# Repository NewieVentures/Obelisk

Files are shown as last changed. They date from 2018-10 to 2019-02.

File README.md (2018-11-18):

# Project Faraday
### By NewieVentures

Remote control of LED strip lights via DMX over cellular.

## Hardware
### Artifacts
* FP1 - Motherboard
* FP2 - DMX expansion module
* FA1 - Assembled unit
* FA2 - Demonstration panel

## LED patterns
To update the pattern of an active device, the device ID and a valid access token is required:

`curl -v "https://api.particle.io/v1/devices/<DEVICE_ID>/<function>" -d access_token=<TOKEN> -d arg=<ARG>`

eg to set a green strobe at 1Hz:

`curl -v "https://api.particle.io/v1/devices/<your device ID here>/strobe" -d access_token=<your access token here> -d arg="1000,#00FF00"`

### Blink
Flash LEDs on and off. Duty cycle controls amount of time on vs off.
#### Arguments
`"<period (ms)>,<duty cycle (0-100)>,<colour-on>,<colour-off>"`

eg blink red 1s:

`POST /v1/devices/:deviceId/blink { "arg": "1000,50,#FF0000,#000000" }`

### Colour
Fixed colour on all leds
#### Arguments
`"<colour>"`

Eg all LEDS blue:

`POST /v1/devices/:deviceId/colour { "arg": "#0000FF" }`

### Gradient
Linear colour gradient
#### Arguments
`"<start-colour>,<end-colour>"`

eg gradient on all LEDS from red to green:

`POST /v1/devices/:deviceId/gradient { "arg": "#FF0000,#00FF00" }`

### Progress
Progress bar
#### Arguments
* Initial value: 0 - (# leds – 1)
* Final value: 1 - #leds
* Direction: 0 = first LED to last, 1 = last LED to first

`"<initial value>,<final value><increment (# leds)>,<increment delay (ms)>,<reset delay(ms)>,<direction>,<colour-on>,<colour-off>"`

eg Progress bar from 0 to 100 leds with 1s between increments, 5s pause at the final value
before repeating and starting from the first LED to the last, incrementing by 1 LED with
RED being on and black being off:

```
POST /v1/devices/:deviceId/progress
{ "arg": "0,100,1,1000,5000,0,#FF0000,#000000" }
```

### Snake
Block of LEDS moving along the strip.
#### Arguments
* Direction: 0 = first LED to last, 1 = last LED to first
`"<period (ms)>,<direction>,<length (# leds)>,<colour-on>,<colour-off>"`

eg Green block of 3 LEDS moving from first LED to last every 5s on a black background:

`POST /v1/devices/:deviceId/snake { "arg": "5000,0,3,#00FF00,#000000" }`

### Strobe
Flash LEDs
#### Arguments
`"<period (ms)>,<colour>"`

eg Blue flash at 1Hz

`POST /v1/devices/:deviceId/strobe { "arg": "1000,#0000FF" }`

## Firmware
The firmware is compiled using the particle cloud development tools (internet connection required).

### Setup
Install the particle CLI, see docs at
https://docs.particle.io/tutorials/developer-tools/cli/

### Compiling
To compile using the particle CLI:
`particle compile electron app --saveTo electron.bin`

### Flashing
To flash a binary to the module over USB, put it into programming mode then:
`particle flash --usb electron.bin`

### Unit tests
```
cd src
make tests && ./tests
```

### Structure
The firmware runs on a Particle Electron board, using their Device OS.  The major firmware modules are:
* cloudFunctions - functions registered with Particle's Device OS on boot and called via their cloud interface.
* LedStripDriver - generates colour values for each LED based on the pattern and settings.  The cloud functions change the pattern settings, while a timer in the RTOS calls the onTimerFired() method to process the new values.
* dmx - uses Serial1 to send the DMX packets (requires some low level override of the baud rate to send the break and mark-after-break at the start of the packet) and sends the NULL start code in each packet.

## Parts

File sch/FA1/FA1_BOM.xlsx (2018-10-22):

Refs | Description | Manufacturer | Order Number | Part Number | Supplier | Quantity | Price | Subtotal | Notes
D1 | LED PANEL INDICATOR RED 1.8V IP67 | E-Switch | EG5379-ND | PVL16FLS11 | Digikey | 1 | $16.49 | $16.49
D2 | LED PANEL INDICATOR BLUE 2.8V IP67 | E-Switch | EG5381-ND | PVL16FLS41 | Digikey | 1 | $16.49 | $16.49
J1 | PWR ENT RCPT IEC320-C14 PANEL QC | Qualtek | Q212-ND | 703W-00/04 | Digikey | 1 | $1.19 | $1.19
J2 | CONN SMA JACK STR 50 OHM SOLDER | Amphenol | ACX1183-ND | 132105 | Digikey | 1 | $11.94 | $11.94
J3 | TERM BLK HEADER 4POS GREEN | Phoenix Contact | 277-6689-ND | 1899155 | Digikey | 1 | $6.49 | $6.49
U1 | FP1 sub-assembly |  |  |  |  | 1 |  | $0.00
U2 | AC/DC CONVERTER 5V 5W | Mean Well | 1866-5411-ND | PS-05-5 | Digikey | 1 | $9.64 | $9.64 | Not required if using PSU on FP1
 | IP65 Sealed ABS enclosure 222x146x55mm | Multicomp | HB-6130 | MC001120 | Jaycar | 1 | $24.95 | $24.95
 | CONN HOUSING VH 2POS 3.96MM WHT | JST | 455-1183-ND | VHR-2N | Digikey | 3 | $0.17 | $0.51
 | CONN HOUSING VH 3POS 3.96MM WHT | JST | 455-1184-ND | VHR-3N | Digikey | 1 | $0.20 | $0.20
 | CONN TERM CRIMP VH/NV 18-22AWG | JST | 455-1133-1-ND | SVH-21T-P1.1 | Digikey | 9 | $0.16 | $1.44
 | Wire |  |  |  |  |  |  |  | Used for LEDs, IEC, SMA and DMX
 | ANT LTE BLADE SWIVEL DIPOLE SMA | Linx Technologies | ANT-LTE-WS-SMA-ND | ANT-LTE-WS-SMA | Digikey | 1 | $13.62 | $13.62
 | Screw M3 x 6mm Pan SS |  |  |  |  | 4 |  | $0.00
 | Washer Flat M3 SS |  |  |  |  | 4 |  | $0.00
 | Screw M3 x 10mm Pan SS |  |  |  |  | 4 |  | $0.00
 | Nut M3 SS |  |  |  |  | 4 |  | $0.00
 | Washer Spring M3 SS |  |  |  |  | 4 |  | $0.00
 | TERM BLOCK PLUG 4POS STR 5.08MM | Phoenix Contact | 277-5925-ND | 1780002 | Digikey | 1 | $8.88 | $8.88
 | CBL ASSY U.FL PLUG to cable 100mm | Hirose Electric Co | H125220-ND | U.FL-LP-066J1-A-(100) | Digikey | 1 | $8.02 | $8.02 | Can use cable from kit (de-solder from PCB antenna)
 |  |  |  |  |  |  | Total | $86.88

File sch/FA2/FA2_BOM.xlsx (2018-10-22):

Refs | Description | Manufacturer | Order Number | Part Number | Supplier | Quantity | Price | Subtotal | Notes
U1 | DMX-512 Decoder SPI output 5-24VDC | LTECH | LT-DMX-1809 | LT-DMX-1809 | Agoeu LED Express Store | 1 | $34.11 | $34.11
U2 | FA1 | Newie Ventures |  |  |  | 1 |  | $0.00
U3 | AC adapter 110-240VAC to 5V 3A DC |  | MP3480 |  | Jaycar | 1 | $24.95 | $24.95
U4, U5 | 5M RGB LED Strip - WS2812 60 Per Meter - White Strip - Weatherproof |  | CE04854 |  | Core Electronics | 0.4 | $69.00 | $27.60
 | Melamine panel |  |  |  |  | 1
 | Power board |  | MS4040 |  | Jaycar | 1 | $5.00 | $5.00
 | IEC cable |  | PS4106 |  |  | 1 | $8.95 | $8.95
 | Screws, wood
 |  |  |  |  |  |  | Total | $91.66

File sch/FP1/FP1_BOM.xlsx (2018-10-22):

Refs | Description | Manufacturer | Order Number | Part Number | Supplier | Quantity | Price | Subtotal | Notes
C1, C5 | CAP CER 1nF 450V C0G 0805 | TDK | 445-15536-1-ND | CGA4C4C0G2W102J060AA | Digikey | 2 | $0.51 | $1.02 | Optional if external 5VDC used
C2 | CAP CER 1UF 50V X7R 0805 | Samsung Electro-mechanics | 1276-6470-1-ND | CL21B105KBFNNNG | Digikey | 1 | $0.20 | $0.20
C3 | CAP ALUM 470UF 20% 10V RADIAL | Kemet | 399-6589-ND | ESH477M010AE3AA | Digikey | 1 | $0.36 | $0.36
C4 | CAP CER 0.1uF 630V X7R 1210 | Kemet | 399-13490-1-ND | C1210C104KBRAC7800 | Digikey | 1 | $0.69 | $0.69
C6 | CAP CER 10UF 10V 10% X5R 0805 | Samsung Electro-mechanics | 1276-2402-1-ND | CL21A106KPCLQNC | Digikey | 1 | $0.30 | $0.30
C7 | CAP CER 0.1UF 50V X7R 0805 | Murata | 490-8049-1-ND | GCM21BR71H104KA37K | Digikey | 1 | $0.33 | $0.33
D1 | TVS DIODE 7Vs 12Vc 600W | Littelfuse | SMBJ7.0ALFCT-ND | SMBJ7.0A | Digikey | 1 | $0.61 | $0.61
F1 | FUSE BOARD MNT 2A 250VAC 125VDC | Schurter | 486-1250-ND | 3403.0169.11 | Digikey | 1 | $0.93 | $0.93 | Optional if external 5VDC used
J1 | CONN HEADER VH TOP 3POS 3.96MM | JST | 455-1640-ND | B3P-VH(LF)(SN) | Digikey | 1 | $0.35 | $0.35 | Optional if external 5VDC used
J2, J4 | CONN HEADER FEMALE 9POS .1\" GOLD | Sullins Connector Solutions | S7042-ND | PPPC091LFBN-RC | Digikey | 4 | $0.97 | $3.88
J3, J5, J6 | CONN HEADER VH TOP 2POS 3.96MM | JST | 455-1639-ND | B2P-VH(LF)(SN) | Digikey | 3 | $0.27 | $0.81
L1 | IND 4.7uH 2A 72 mOHM SMD | Taiyo Yuden | 587-2407-1-ND | NRS5020T4R7MMGJ | Digikey | 1 | $0.49 | $0.49 | Optional if external 5VDC used
L2 | Common Mode Choke 10mH 2A 2 lines through hole | Schaffner | 817-2142-ND | RN143-2-02-10M | Digikey | 1 | $4.18 | $4.18 | Optional if external 5VDC used
PS1 | AC-DC 100-240VAC to 5VDC 2A and 12V 400mA | Mornsun | LHE15-20D0512-04 | LHE15-20D0512-04 | Mornsun | 1 |  | $0.00 | Optional if external 5VDC used
R1, R2 | RES SMD 4.7K OHM 5% 1/8W 0805 | Yageo | 311-4.7KARCT-ND | RC0805JR-074K7L | Digikey | 2 | $0.14 | $0.28
R3, R4 | RES SMD 220 OHM 5% 0.4W 0805 | Rohm | RHM220KCT-ND | ESR10EZPJ221 | Digikey | 2 | $0.14 | $0.28
RV1 | VARISTOR 470V 4.5KA DISC 14MM | Bourns | MOV-14D471K-ND | MOV-14D471K | Digikey | 1 | $0.68 | $0.68 | Optional if external 5VDC used
U1 | Particle Electron 3G Kit | Particle | CE04423 | Electron | Core Electronics | 1 | $135.00 | $135.00
J2, J4 | CONN HEADER FEMALE 4POS .1\" GOLD | Sullins Connector Solutions | S7037-ND | PPPC041LFBN-RC | Digikey | 4 | $0.68 | $2.72
 |  |  |  |  |  |  | Total | $153.11

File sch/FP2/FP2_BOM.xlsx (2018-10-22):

Refs | Description | Manufacturer | Order Number | Part Number | Supplier | Quantity | Price | Subtotal | Notes
C1 | CAP CER 10UF 10V X5R 0805 | Samsung Electro-mechanics | 1276-2402-1-ND | CL21A106KPCLQNC | Digikey | 1 | $0.30 | $0.30
C2 | CAP CER 0.1UF 50V X7R 0805 | Murata | 490-8049-1-ND | GCM21BR71H104KA37K | Digikey | 1 | $0.33 | $0.33
D1, D2 | TVS DIODE 43V 69.4V DO214AA | Littelfuse | SMBJ43CALFCT-ND | SMBJ43CA | Digikey | 2 | $0.84 | $1.68
J1 | TERMINAL BLOCK 5.08MM 3POS PCB | On Shore Technology | ED2903-ND | OSTYC032150 | Digikey | 1 | $1.55 | $1.55
J2 | CONN HEADER MALE 18POS .1\" | Amphenol FCI | 609-5513-ND | 68001-418HLF | Digikey | 1 | $0.87 | $0.87
R1, R5, R6 | RES SMD 10K OHM 1% 1/8W 0805 | Yageo | 311-10.0KCRCT-ND | RC0805FR-0710KL | Digikey | 3 | $0.14 | $0.42
R2, R4 | RES SMD 10 OHM 5% 0.4W 0805 | Rohm | RHM10KCT-ND | ESR10EZPJ100 | Digikey | 2 | $0.14 | $0.28
R3 | RES SMD 120 OHM 5% 0.4W 0805 | Rohm | RHM120KCT-ND | ESR10EZPJ121 | Digikey | 1 | $0.14 | $0.14
U1 | IC TXRX RS485 HALF DUPLEX 8SOIC | MaxLinear | 1016-1827-6-ND | SP485EEN-L/TR | Digikey | 1 | $1.46 | $1.46
 |  |  |  |  |  |  | Total | $7.03

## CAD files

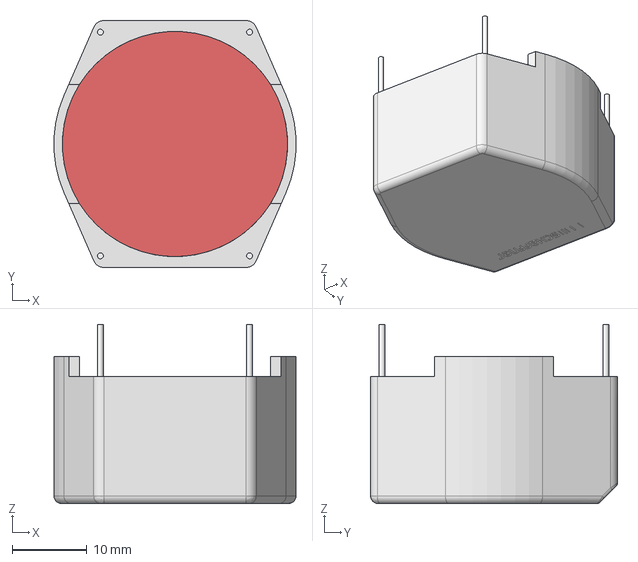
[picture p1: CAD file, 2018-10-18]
sch/3D files/RN143-x-02.stp
32.4 x 33.1 x 24.0 mm

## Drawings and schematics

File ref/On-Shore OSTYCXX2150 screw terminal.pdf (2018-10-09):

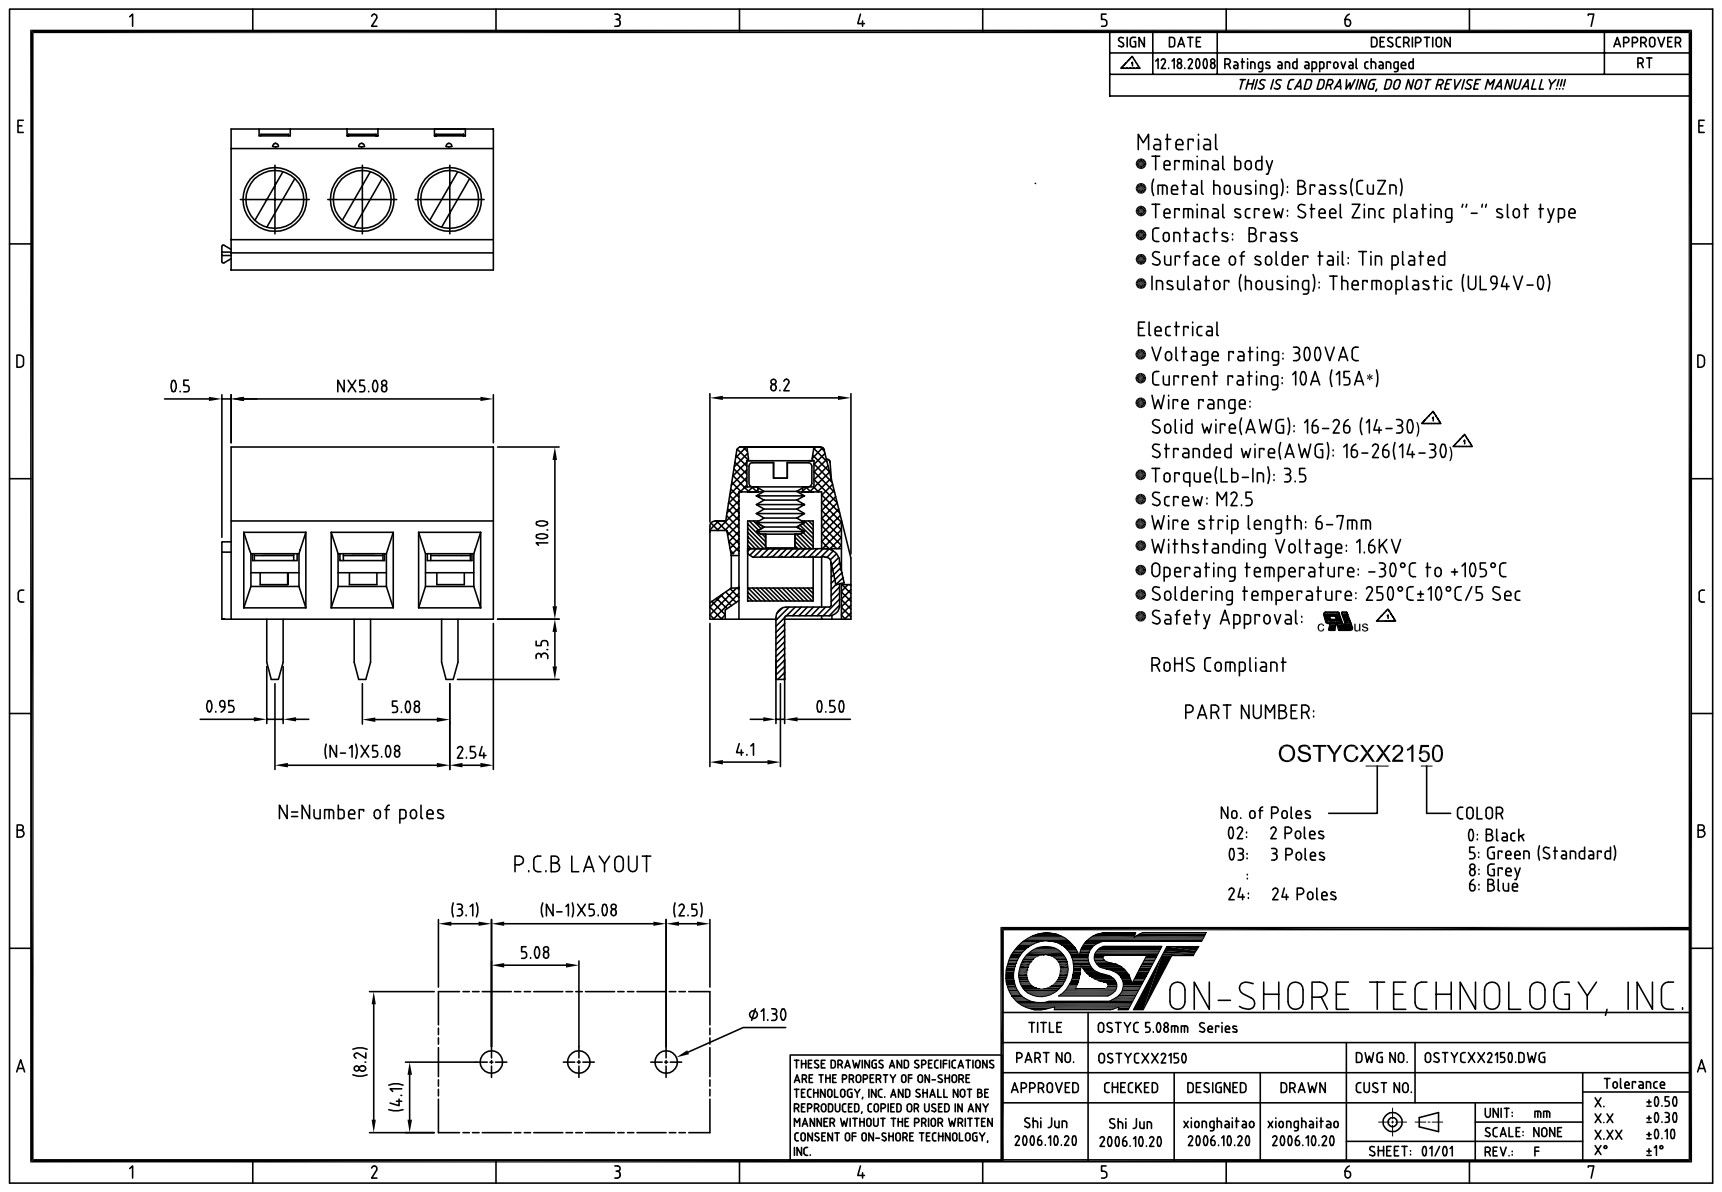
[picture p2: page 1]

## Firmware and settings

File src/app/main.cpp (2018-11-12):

#include "Particle.h"

#include "serialDebug.h"
#include "ledStrip.h"
#include "cloudFunctions.h"
#include "statusLed.h"
#include "config.h"
#include "events.h"
#include "timers.h"

//run user code on boot to drive status LED
SYSTEM_MODE(SEMI_AUTOMATIC);

static const String LOG_MODULE = "MAIN";

static CloudFunctions *cloudFunctions;

int regFn(String name, int (CloudFunctions::*cloudFn)(String arg), CloudFunctions *cls) {
  return Particle.function(name, cloudFn, cls);
}

void setup() {
  statusLed::setup();
  ledStrip::setup();
  events::setup();
  timers::setup();

  cloudFunctions = new CloudFunctions(ledStrip::getDriver(), &regFn);

  Particle.connect();
}

/* Note: Code that blocks for too long (like more than 5 seconds), can make
 * weird things happen (like dropping the network connection).  The built-in
 * delay function shown below safely interleaves required background activity,
 * so arbitrarily long delays can safely be done if you need them.
 */
void loop() {
}

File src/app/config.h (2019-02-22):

#ifndef OBELISK_CONFIG_H
#define OBELISK_CONFIG_H

#define NUM_LEDS 18
#define COLOURS_PER_LED 3

#define TIMER_RESOLUTION_MS 25

#define COLOURS_PER_LED 3
#define PWM_DUTY_STEPS 10

/* #define COLOUR_ORDER_RRGGBB */
#define COLOUR_ORDER_GGRRBB

/**********************************
 * Status LED
 *********************************/
#define PIN_STATUS_LED D3
#define TIMER_RESOLUTION_STATUS_LED_MS 100

#define STATUS_RAPID_FLASH_PERIOD_MS 200
#define STATUS_FLASH_PERIOD_MS 500
#define STATUS_SLOW_FLASH_PERIOD_MS 2000
#define STATUS_BLINK_PERIOD_MS 3000

/*********************************************************************************
 *  Calculated values
 ********************************************************************************/

#ifdef COLOUR_ORDER_GGRRBB
  #define INDEX_GREEN 0
  #define INDEX_RED 1
  #define INDEX_BLUE 2
#else
  #define INDEX_RED 0
  #define INDEX_GREEN 1
  #define INDEX_BLUE 2
#endif

#endif

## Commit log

2018-10-08 Initial code commit. LED driver code in progress.
2018-10-08 Initial hardware design commit. Schematics and PCB for module done.
    [dmx_module.kicad_pcb, dmx_module.sch, light_controller.kicad_pcb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]
2018-10-09 Updated schematic and PCB based on feedback: - Used 'value' instead of ref for test points - Hid mounting hole refs on PCB - Updated electron footprint to clearly indicate correct mounting position -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
    [light_controller.kicad_pcb, light_controller.sch]
2018-10-09 Adding datasheets for components on PCB so far.
2018-10-09 Added missing courtyards, hid MH refs, fixed DRC errors.
    [light_controller.kicad_pcb]
2018-10-10 Updated MB SCH - C1 symbol (NP), part info, module connector.
    [dmx_module.sch]
2018-10-10 Updated DMX module PCB based on schematic and footprint changes.
    [dmx_module.kicad_pcb]
2018-10-10 Updated U1 footprint on DMX module to SOIC-8.
    [dmx_module.kicad_pcb, dmx_module.sch]
2018-10-10 Changed C6 on motherboard schematic to non-polarised symbol.
    [light_controller.sch]
2018-10-10 Minor routing update on DMX module PCB.
    [dmx_module.kicad_pcb]
2018-10-16 Updated TVS footprints on DMX module to remove polarisation markings. Changed sch lib path to relative.
    [dmx_module.kicad_pcb, dmx_module.sch]
2018-10-16 Updated motherboard: - Added RN143 footprint, standard is not correct for part. - Fixed fuse footprint to match datasheet. - Updated mounting hole positions based on measurements and re-routed. - Upd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
    [light_controller.kicad_pcb, light_controller.sch]
2018-10-16 Changed GND test point to 3mm hole.
    [light_controller.kicad_pcb, light_controller.sch]
2018-10-17 Ignore kicad backup files.
2018-10-18 Added LED mounting connectors to SCH and PCB. Changed GND testpoint to take an alligator clip and multimeter probe. Rounded PCB edges.
    [light_controller.kicad_pcb, light_controller.sch]
2018-10-18 Made DMX module lib path relative to project. Added SOIC-8 footprint to project_parts. Fixed DMX module board outline issue (extra Edge.Cuts track).
    [dmx_module.kicad_pcb]
2018-10-18 Added 3D model for RN143.
    [RN143-x-02.stp]
2018-10-18 Rounded board edge of DMX module PCB.
    [dmx_module.kicad_pcb]
2018-10-18 Removed unused SO-8 footprint.
2018-10-18 Renamed folders/files as per new coding convention (see README). Added FA1 and FA2 schematics. Updated all schematic title blocks.
    [FA1.sch, FA2.sch, FP1.kicad_pcb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]
2018-10-22 Completed BOMs and changed module connector name to 'Faraday_module'
    [FA1.sch, FA1_BOM.xlsx, FA2.sch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]
2018-10-22 Updated FA1 BOM - Added receptacle and pins for board connectors
    [FA1_BOM.xlsx]
2018-10-22 Got existing ledStripDriver tests passing.
2018-10-23 Added gerbers for FP1 and FP2
    [FP1-B.Cu.gbr, FP1-B.Mask.gbr, FP1-B.Paste.gbr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]
2018-10-29 Switched to using Particle String class everywhere, stubbed in tests.
2018-10-29 Fixed bug with progress pattern where last LED was never on.
2018-11-07 Refactored handleSnakePattern in ledStripDriver.
2018-11-11 Made LED colour order configurable, centralised configuration.
2018-11-12 Implemented status LED and refactored main.cpp into separate files.
2019-01-21 Fixed bug with 'progress' - if final val < NUM_LEDS, leds > final would be on.
2019-02-19 Started weather pattern, implemented temperature layer.
